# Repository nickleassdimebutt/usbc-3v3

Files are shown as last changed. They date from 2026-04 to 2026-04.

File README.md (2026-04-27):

# usbc-3v3

USB-C → 3.3V LDO power board.  
Input: 5V USB-C (HRO TYPE-C-31-M-12). Output: 3.3V @ up to 800mA (AMS1117-3.3).  
Board size: 50×30mm. 2-layer, JLCPCB-compatible.

## Bill of Materials

| Ref | Value | Footprint |
|-----|---|---|
| J1  | HRO TYPE-C-31-M-12 | USB-C receptacle |
| U1  | AMS1117-3.3 | SOT-223 |
| R1, R2 | 5.1kΩ | 0402 — CC pull-downs |
| C1, C2 | 10µF/10V | 0805 — VBUS bypass |
| C3  | 10µF/10V | 0805 — 3V3 output bulk |
| C4  | 100nF | 0402 — 3V3 output bypass |
| R3  | 1kΩ | 0402 — LED current limit |
| D1  | RED LED | 0805 |
| J2  | 3V3_OUT | 2-pin 2.54mm header |
| H1–H4 | — | M2 mounting holes |

---

## Verification & Bringup

### Running verification

```bash
# DRC only (fast — always run before ordering)
./verify.sh

# DRC + gerbers + drill + CPL + BOM
./verify.sh --fab

# Above + iBOM + 3D renders (needs extra KiBot deps — Linux recommended)
./verify.sh --all
```

Exit code 0 = all checks passed. Exit code 1 = one or more failures.

### Output locations

| Directory | Contents | Committed to git |
|---|---|---|
| `output/drc/` | DRC report (`drc_report.txt`) | ✅ yes |
| `output/render/` | 3D PNG renders (top + bottom) | ✅ yes |
| `output/ibom/` | Interactive HTML BOM | ✅ yes |
| `output/docs/` | Schematic PDF | ✅ yes |
| `output/fab/` | Gerbers, drill, CPL, BOM | ❌ no — rebuild on demand |

Committed outputs let you **diff what changed** between revisions:
```bash
git diff v1.0..v1.1 -- output/drc/drc_report.txt   # did DRC errors change?
git diff v1.0..v1.1 -- output/render/render_top.png # did the layout change?
```

### After assembly — filling out bringup.md

1. Open `bringup.md`
2. Work through each section in order (visual → continuity → smoke → rails → functional)
3. Fill in the **measured** and **pass/fail** columns as you go
4. Commit the completed checklist: `git add bringup.md && git commit -m "bringup: rev X pass"`

The checklist is pre-populated with expected values derived from the schematic (CC pull-down = 5.1kΩ to GND, 3V3 rail = 3.235–3.365V, quiescent current ≈6–10mA, etc.).

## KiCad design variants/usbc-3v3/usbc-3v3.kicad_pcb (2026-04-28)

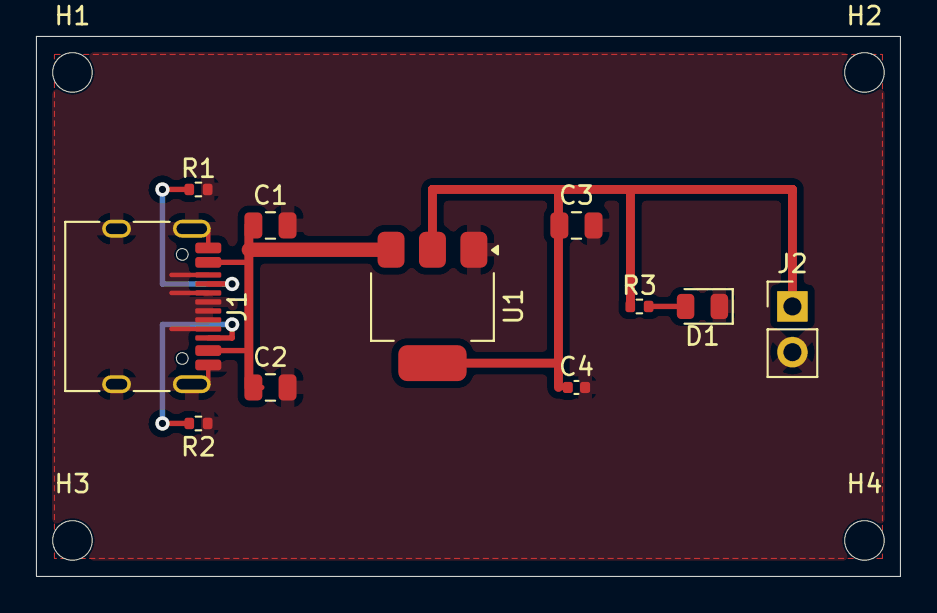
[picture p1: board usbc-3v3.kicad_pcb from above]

Board: 2 copper layers, 48.0 x 30.0 mm, 15 parts (0 on the bottom side), 6 nets.

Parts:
C1, C2, C3: 10uF; C_0805_2012Metric
C4: 100nF; C_0402_1005Metric
D1: RED; LED_0805_2012Metric
H1, H2, H3, H4: MountingHole_M2; MountingHole_2.2mm_M2
J1: HRO TYPE-C-31-M-12; USB_C_Receptacle_HRO_TYPE-C-31-M-12
J2: 3V3_OUT; PinHeader_1x02_P2.54mm_Vertical
R1, R2: 5.1k; R_0402_1005Metric
R3: 1k; R_0402_1005Metric
U1: AMS1117-3.3; SOT-223-3_TabPin2

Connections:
+3V3: C3.1, C4.1, J2.1, R3.1, U1.2
CC1: J1.A5, R1.1
CC2: J1.B5, R2.1
GND: C1.2, C2.2, C3.2, C4.2, D1.1, J1.A1, J1.A6, J1.A7, J1.A8, J1.A12, J1.B1, J1.B6, J1.B7, J1.B8, J1.B12, J1.SH, J2.2, R1.2, R2.2, U1.1
N_D1: D1.2, R3.2
VBUS: C1.1, C2.1, J1.A4, J1.A9, J1.B4, J1.B9, U1.3

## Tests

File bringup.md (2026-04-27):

# USB-C → 3.3V LDO — Bringup Checklist

Board: `usbc-3v3`  
Schematic nets: `VBUS` (5V in), `GND`, `+3V3` (LDO out), `CC1`, `CC2`, `N_LED`  
Fill in **measured** and **pass/fail** columns during bringup.

---

## 1. Visual Inspection (before powering on)

- [ ] J1 (USB-C) — seated flush, no solder bridges between SMD signal pads — expected: no bridges — measured: ___ — pass/fail: ___
- [ ] J1 shield PTH pins (2×) — fully soldered, not lifted — expected: solid fillet — measured: ___ — pass/fail: ___
- [ ] U1 (AMS1117-3.3, SOT-223) — pin 1 (GND) at bottom, large tab (VOUT/pin 2) centred — expected: correct orientation per silkscreen arrow — measured: ___ — pass/fail: ___
- [ ] U1 tab pad — soldered to large centre pad, no voids visible — expected: ≥75% coverage — measured: ___ — pass/fail: ___
- [ ] R1, R2 (5.1kΩ 0402, CC resistors) — placed left of J1, one above/below centre — expected: no tombstoning — measured: ___ — pass/fail: ___
- [ ] C1, C2 (10µF 0805, VBUS bypass) — near J1, correct polarity if electrolytic (these are ceramic — no polarity) — expected: flat, no tilt — measured: ___ — pass/fail: ___
- [ ] C3 (10µF 0805, 3V3 output bulk) — right of U1 — expected: no solder bridges — measured: ___ — pass/fail: ___
- [ ] C4 (100nF 0402, 3V3 output bypass) — adjacent to C3 — expected: no solder bridges — measured: ___ — pass/fail: ___
- [ ] R3 (1kΩ 0402, LED current limit) — between C3 and D1 — expected: no tombstoning — measured: ___ — pass/fail: ___
- [ ] D1 (LED 0805, red) — cathode (line on package) toward J2 side — expected: correct orientation per silkscreen — measured: ___ — pass/fail: ___
- [ ] J2 (2-pin 2.54mm header) — right edge, pin 1 square pad = +3V3 — expected: pins straight — measured: ___ — pass/fail: ___
- [ ] H1–H4 (M2 mounting holes) — four corners, no solder in holes — expected: clear — measured: ___ — pass/fail: ___
- [ ] GND copper pour — visible on F.Cu between components — expected: continuous flood — measured: ___ — pass/fail: ___

---

## 2. Continuity Checks (DMM in continuity/diode mode, board unpowered)

- [ ] USB-C shield (J1 NPTH pins) to GND (J2 pin 2) — expected: 0Ω (continuity beep) — measured: ___ — pass/fail: ___
- [ ] J1 A1/A12/B1/B12 (GND pins) to J2 pin 2 (GND) — expected: 0Ω — measured: ___ — pass/fail: ___
- [ ] J1 A4/B9 (VBUS pins) to C1 pad 1 (VBUS) — expected: 0Ω — measured: ___ — pass/fail: ___
- [ ] J1 A5 (CC1) to R1 pin 1 — expected: 0Ω — measured: ___ — pass/fail: ___
- [ ] J1 B5 (CC2) to R2 pin 1 — expected: 0Ω — measured: ___ — pass/fail: ___
- [ ] R1 pin 2, R2 pin 2 to GND — expected: 0Ω — measured: ___ — pass/fail: ___
- [ ] U1 pin 3 (VIN) to VBUS net — expected: 0Ω — measured: ___ — pass/fail: ___
- [ ] U1 pin 1 (GND) to GND — expected: 0Ω — measured: ___ — pass/fail: ___
- [ ] U1 pin 2/tab (VOUT) to J2 pin 1 (+3V3) — expected: 0Ω — measured: ___ — pass/fail: ___
- [ ] VBUS to GND (short check) — expected: >10kΩ (no short) — measured: ___ — pass/fail: ___
- [ ] +3V3 to GND (short check) — expected: >1kΩ (caps → shows charging, not short) — measured: ___ — pass/fail: ___

---

## 3. Smoke Test (current-limited bench supply)

Set supply to **5.0V, current limit 100mA** before connecting.

- [ ] Connect bench supply + to J1 VBUS / − to GND (or use USB-C cable to a USB power meter) — expected: no smoke, no burning smell — measured: ___ — pass/fail: ___
- [ ] Inrush current settles — expected: current drops to steady-state within 100ms — measured: ___ — pass/fail: ___
- [ ] Steady-state current at 5V, no load — expected: 6–10mA (AMS1117 Iq ≈5mA + LED ≈1.3mA) — measured: ___ mA — pass/fail: ___
- [ ] D1 (red LED) illuminates — expected: lit, red — measured: ___ — pass/fail: ___
- [ ] U1 temperature after 60s, no load — expected: warm but not hot (<50°C) — measured: ___ °C — pass/fail: ___

---

## 4. Power Rail Checks (DMM, board powered at 5V)

- [ ] VBUS rail — probe C1/C2 pad 1 (+) to GND — expected: 4.75–5.25V — measured: ___ V — pass/fail: ___
- [ ] +3V3 rail — probe J2 pin 1 (+) to J2 pin 2 (GND), or C3 pad 1 to GND — expected: 3.235–3.365V (AMS1117 ±2%) — measured: ___ V — pass/fail: ___
- [ ] CC1 — probe R1 pad 1 to GND — expected: ~0V (pulled to GND via R1=5.1kΩ, USB host sources CC) — measured: ___ V — pass/fail: ___
- [ ] CC2 — probe R2 pad 1 to GND — expected: ~0V same — measured: ___ V — pass/fail: ___
- [ ] N_LED (anode of D1 / R3 pad 2) — expected: +3V3 − Vf_LED ≈ 1.2–1.5V — measured: ___ V — pass/fail: ___

---

## 5. Functional Tests

- [ ] **3V3 line regulation** — vary input 4.75V→5.25V, measure +3V3 — expected: <±0.1V variation — measured: ___ — pass/fail: ___
- [ ] **3V3 load test** — attach 330Ω load across J2 (≈10mA load) — expected: +3V3 stays ≥3.235V — measured: ___ V — pass/fail: ___
- [ ] **3V3 load test (max)** — attach 33Ω load across J2 (≈100mA), U1 max 800mA — expected: +3V3 stays ≥3.235V, U1 <70°C — measured: ___ V / ___ °C — pass/fail: ___
- [ ] **Power dissipation check** at 100mA load — U1 dissipates (5V−3.3V)×0.1A = 170mW — expected: U1 warm but not burning — measured: ___ — pass/fail: ___
- [ ] **Ripple** — scope +3V3 with 100mA load — expected: <50mV pk-pk — measured: ___ mV — pass/fail: ___
- [ ] **J2 output header** — confirm pin 1 = +3V3, pin 2 = GND with DMM — expected: 3.3V between pins — measured: ___ V — pass/fail: ___

---

## Notes

_Space for any anomalies found during bringup:_

```
Date: ___________
Tester: ___________
Supply used: ___________
Notes:
```

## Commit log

2026-04-27 feat: add verification pipeline and bringup checklist
    - .kibot.yaml: KiBot config for gerbers/drill/CPL (Windows-compatible)
    - scripts/gen_bom.py: pcbnew-based BOM generator (no schematic needed)
    - verify.sh: one-command DRC (kicad-cli) + fab outputs; exits non-zero on failure
    - bringup.md: board-specific checklist with expected values for all rails/tests
    - README.md: project overview + verification & bringup guide
    - .gitignore: excludes lock files, backups, output/fab/
    - output/drc/: DRC report committed (0 violations, 0 unconnected)
    verify.sh --fab: 5/5 PASS (DRC, gerbers, drill, CPL, BOM)
    [usbc-3v3.kicad_pcb]
2026-04-28 feat: port to circuit_toolkit (three-file design pattern)
    Replaces monolithic scripts/build_board.py with:
    - circuit.py — topology in 25 lines using circuit_toolkit blocks
    - layout.py — positions + tracks + vias + zones (extracted from existing PCB)
    - build.py — orchestrator (15 lines)
    scripts/build_board.py kept as historical reference.
    Outputs (verified via verify.sh --fab, 5/5 PASS):
    - usbc-3v3.kicad_pcb (DRC: 0 errors, 44 cosmetic silk warnings)
    - output/docs/schematic.svg (auto-generated by netlistsvg)
    - output/fab/bom/{bom,bom_jlcpcb}.csv (with LCSC numbers)
    verify.sh updated to distinguish DRC errors from warnings.
    Round-trip workflow:
    1. Edit circuit.py for topology / layo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
    [usbc-3v3.kicad_pcb]
2026-04-28 build: rebuild after LCSC-hide fix
    DRC now reports 0 errors, 0 warnings (silk overlaps were caused by
    visible LCSC text on every component; now hidden by default).
    [usbc-3v3.kicad_pcb]
2026-04-28 build: regenerate datasheet PDF + 3D renders for circuit_toolkit v2
    datasheet.pdf is the LT-style 10-page output with the schematic page
    now rendering (svglib SVG→PNG conversion shipped in toolkit).
    .gitattributes added so PDFs/PNGs are stored as binary regardless of
    core.autocrlf; preview/ pages excluded as they regenerate via pdftoppm.
2026-04-28 build: --datasheet / --sim modes in build.py + verify.sh
    build.py grows argparse: default still emits PCB + schematic + BOM,
    --sim adds the six SPICE pre-flights, --datasheet adds 3D renders +
    the LT-style PDF, both flags compose so a single pass produces the
    complete v2 deliverable set with sim plots embedded as section 7.0.
    verify.sh now parses mode flags positionally and supports --datasheet
    and --sim alongside the existing --fab and --all. Each mode checks
    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
2026-04-28 feat: variant support — usbc-3v3 / -5v0 / -1v8 from one source
    circuit.py grows output_v parameter; layout.py wraps positions/tracks/
    vias/zones in get_layout(output_net) so the same physical board (SOT-223
    LDO same footprint across the AMS1117 family) can swap rails. build.py
    takes --variants 3.3 5.0 1.8 to build the whole product line in one
    pass; default with no flag preserves the canonical 3.3V build at the
    project root. Variant outputs land at variants/<name>/{name.kicad_pcb,
    output/...}. All three variants verified DRC-clean.
    [usbc-1v8.kicad_pcb, usbc-3v3.kicad_pcb, usbc-5v0.kicad_pcb]
2026-04-28 ci: add GitHub Actions verify workflow + portable tooling paths
    verify.yml runs DRC + fab + sim + datasheet on Ubuntu 24.04, installs
    KiCad 9 (same .kicad_pcb format as 10), ngspice, netlistsvg, and
    pip-installs circuit_toolkit[docs,sim] from the toolkit repo. Uploads
    all artefacts on every run so PR reviewers can download the rebuilt
    PCB / datasheet / sim plots without running locally.
    verify.sh now reads KICAD_CLI / KICAD_PY / KIBOT from env so the same
    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
2026-04-28 ci+build: fix CI pip URL syntax + integrate pcbdraw into datasheet
    CI was failing because pip parsed `[docs,sim]` as part of the URL
    fragment instead of as PEP 508 extras. Use the standalone form:
    circuit_toolkit[docs,sim] @ git+...
    build.py grows a pcbdraw call before build_datasheet — produces
    output/render/pcbdraw_{front,back}.{svg,png} and feeds the PNGs as
    new pcbdraw_{front,back} kwargs to build_datasheet so section 3.1
    "PCB Stylized View" populates. Datasheet jumps to 11 pages without
    sim, 14 with sim.
2026-04-28 ci: install cairo dev + inkscape for pcbdraw build chain
    pycairo (transitive dep via pcbdraw → svgpathtools → cairo SVG
    backend) needs libcairo2-dev to compile its C extension on Linux.
    Adding inkscape too so pcbdraw's PNG export uses high-fidelity
    inkscape conversion instead of svglib (which loses some styling).
2026-04-28 build: hierarchical schematic in datasheet (overview + 4 block details)
    build.py calls build_hierarchical_schematic() before build_datasheet()
    when --datasheet is set, passing the resulting {"overview": ..., bid:
    ...} dict as schematic_blocks. Datasheet section 2.0 grows from 1
    page to 5 — overview + ldo + usbc_power + led + header.
    mounting-hole detail is skipped because it has no electrical content
    for netlistsvg.
2026-04-28 ci: trigger rebuild against toolkit d97da1d (KiCad 9 compat)
2026-04-28 ci: install full KiCad library set + footprint debug step
2026-04-28 ci: trigger rebuild against toolkit 86ad739 (kicad-cli auto-detect)
